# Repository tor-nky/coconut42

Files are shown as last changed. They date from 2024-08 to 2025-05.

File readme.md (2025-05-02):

# coconut42 - split ortholinear keyboard
coconut42 は左右分割式、格子配列のキーボードです。
片側ごとのキーは縦3x横6+親指3個、両側で42キーです。
本キーボードはfoostan氏が設計されたCorne Cherryのv4.1、v3-final、v2.1の公開情報を活用させていただき、キー配列とマイコンボードを変更したものです。
foostan氏のご厚意に感謝いたします。

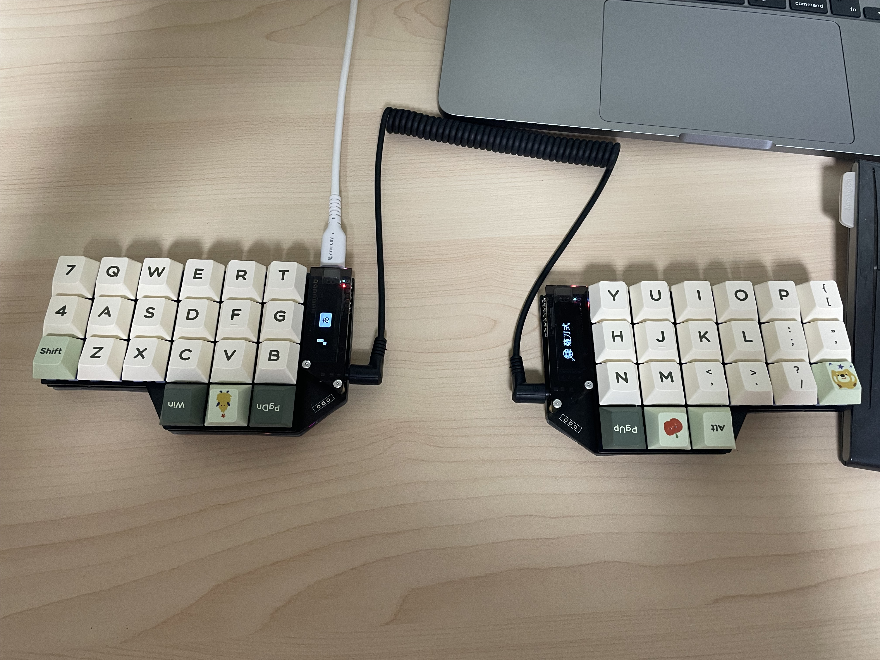
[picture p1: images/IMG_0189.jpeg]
coconut42


## 部品
### 必須
|名前|数|備考|
|:-|:-|:-|
|PCB|2枚||
|トッププレート|2枚||
|ボトムプレート|2枚||
|Seeed Studio XIAO RP2040|2枚||
|TRRSジャック|2個|MJ-4PP-9|
|ダイオード|50個|1N4148W SOD123|
|Kailh PCBソケット|42個|MX用|
|キースイッチ|42個|CherryMX互換にのみ対応 |
|キーキャップ|42個|1u|
|スペーサー M2 7.5mm全ネジ|10本||
|ネジ M2 4mm|20本||
|クッションゴム|8個||
|TRS(3極)ケーブル|1本|TRRS(4極)ケーブルでも可 |
|USB type Cケーブル |1本||
### 任意
| 名前 | 数 | 備考 |
|:-|:-|:-|
|リード線 2cm程度|2本|LEDとOLEDの電源供給用|
|抵抗1/6W470Ω|2本|R1,R6で。小さいサイズも可。やむを得ない場合ジャンパー|
|WS2812B|12個|下向き実装|
|YS-SK6812MINI-E|42個|上向き実装|
|OLEDモジュール|2枚||
|ピンヘッダ 4連|2個||
|ピンソケット4連|2個||
|OLEDカバー|2枚|Corne Cherryのものと交換可能|
|スペーサー M2 9mm全ネジ|4本||
|ネジ M2 4mm|4本||
## 注意点
* LEDまたはOLEDを取り付ける場合は、マイコンボードの裏にある「VIN」とPCBの「VIN(-r)」をリード線でつなぐ必要があります。
* LEDを取り付ける場合は、R1とR6も取り付けます。  
470Ωを入れるのは、電源供給が一瞬途絶えたときの安全対策です。
* R2,R7は、Seeed Studio XIAO ESP32C3対応を考えたためです。
* C7〜C27,C34〜C54,R3〜R5,R8〜R10は、ノイズ対策が必要になれば取り付けます。
* PCB上面のC1〜C6,C28〜C33、PCB下面のOLEDソケットそばのC55,C56は __不要__ です。
* 向きを間違えればマイコンボードを壊すので、回路図、PCBに保護ダイオードを書きませんでした。
## 別のマイコンボードへの対応
おすすめできませんが、できるものもあります。
### Seeed Studio XIAO nRF52840
ZMK Firmwareが改良二乗マトリクスに対応しています。[設定例](https://github.com/tor-nky/zmk-coconut42-ble)  
LEDは光らせられませんでした（仮にできたとしても、Blutooth通信の低下になるという）  
[左側の裏を写した写真](images/IMG_0218.jpeg) [右側の裏を写した写真](images/IMG_0215.jpeg)(マイコンボード故障でリカバリ箇所あり)
* OLED、TRRSジャックはつけない。リチウムイオン充電池を両面テープで貼り付け、プラス線は BAT+ につなぐ。マイナス線からは BAT- につなぐ途中にリセッタブルヒューズと電源スイッチを入れる。
* 左右間通信はBluetoothで行う。
* キーを押していないときにはマイコンを眠らせたいので、[Low Power Improved Square Matrix](https://kbd.news/Low-Power-Improved-Square-Matrix-1810.html)の[この回路図](https://kbd.news/pic/article/1810/4-pin-improved-square-matrix-low-power.png)のようにダイオードをマイコン取り付け部の下側につける。  
割り込みピンは左右間通信用だった「data」を流用する。
* VINにはVBUSをつなぐ
### Seeed Studio XIAO ESP32C3/6
使用できません。
### Waveshare RP2040-Zero
* 電源ピンを合わせるため、裏返してコンスルーピンヘッダを介してハンダ付けし、ピンの機能に合わせてプログラムを作り替えれば動くと思われる。
* VINにはVSYS(5V)をつなぐ
* マイコンボードを外さなければ、ファームウェアを書き込むリセットができません

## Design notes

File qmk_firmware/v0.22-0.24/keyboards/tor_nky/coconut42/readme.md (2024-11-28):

# coconut42 Keyboard

A split keyboard with 3x6 ortholiner keys and 3 thumb keys.

Keyboard Maintainer: [tor-nky](https://github.com/tor-nky/)
Hardware Supported: Seeed XIAO RP2040
Hardware Availability: [PCB & Case Data](https://github.com/tor-nky/coconut42)

Make example for this keyboard (after setting up your build environment):

```sh
make tor_nky/coconut42:default
```

See the [build environment setup](https://docs.qmk.fm/#/getting_started_build_tools) and the [make instructions](https://docs.qmk.fm/#/getting_started_make_guide) for more information. Brand new to QMK? Start with our [Complete Newbs Guide](https://docs.qmk.fm/#/newbs).

## Bootloader

The controller board have a reset and boot buttons next to the TRRS jack to enter in to the bootloader.

Additionally, if you hold down the "Q" or "P" buttons when plugging in that half of the keyboard (per the default QWERTY layout), this will jump to the bootloader and reset the EEPROM (persistent storage).  This would normally be the very top corner-most position, but due to the breakaway column, it's left at Q and P for compatibility. 

## RGB Matrix 
The coconut42 Keyboard also supports using the RGB Matrix feature, in place of RGB Light.  This provides a better experience when using the keyboard, as it supports a number of per key effects properly.  If you're not using the in switch LEDs, then you may want to pass on doing this. 

In your keymap's `rules.mk` file, add the following: 

```make
RGBLIGHT_ENABLE = no
RGB_MATRIX_ENABLE = yes
```

And in your `config.h` file, add the following:

```c

#ifdef RGB_MATRIX_ENABLE
#   define RGB_MATRIX_KEYPRESSES // reacts to keypresses
// #   define RGB_MATRIX_KEYRELEASES // reacts to keyreleases (instead of keypresses)
#   define RGB_MATRIX_SLEEP // turn off effects when suspended
#   define RGB_MATRIX_FRAMEBUFFER_EFFECTS
// #   define RGB_MATRIX_LED_PROCESS_LIMIT (RGB_MATRIX_LED_COUNT + 4) / 5 // limits the number of LEDs to process in an animation per task run (increases keyboard responsiveness)
// #   define RGB_MATRIX_LED_FLUSH_LIMIT 16 // limits in milliseconds how frequently an animation will update the LEDs. 16 (16ms) is equivalent to limiting to 60fps (increases keyboard responsiveness)
#    define RGB_MATRIX_MAXIMUM_BRIGHTNESS 150 // limits maximum brightness of LEDs to 150 out of 255. Higher may cause the controller to crash. 
#    define RGB_MATRIX_HUE_STEP 8
#    define RGB_MATRIX_SAT_STEP 8
#    define RGB_MATRIX_VAL_STEP 8
#    define RGB_MATRIX_SPD_STEP 10

/* Enable the animations you want/need.  You may need to enable only a small number of these because       *
 * they take up a lot of space.  Enable and confirm that you can still successfully compile your firmware. */
// RGB Matrix Animation modes. Explicitly enabled
// For full list of effects, see:
// https://docs.qmk.fm/#/feature_rgb_matrix?id=rgb-matrix-effects
#    define ENABLE_RGB_MATRIX_ALPHAS_MODS
#    define ENABLE_RGB_MATRIX_GRADIENT_UP_DOWN
#    define ENABLE_RGB_MATRIX_GRADIENT_LEFT_RIGHT
#    define ENABLE_RGB_MATRIX_BREATHING
#    define ENABLE_RGB_MATRIX_BAND_SAT
#    define ENABLE_RGB_MATRIX_BAND_VAL
#    define ENABLE_RGB_MATRIX_BAND_PINWHEEL_SAT
#    define ENABLE_RGB_MATRIX_BAND_PINWHEEL_VAL
#    define ENABLE_RGB_MATRIX_BAND_SPIRAL_SAT
#    define ENABLE_RGB_MATRIX_BAND_SPIRAL_VAL
#    define ENABLE_RGB_MATRIX_CYCLE_ALL
#    define ENABLE_RGB_MATRIX_CYCLE_LEFT_RIGHT
#    define ENABLE_RGB_MATRIX_CYCLE_UP_DOWN
#    define ENABLE_RGB_MATRIX_RAINBOW_MOVING_CHEVRON
#    define ENABLE_RGB_MATRIX_CYCLE_OUT_IN
#    define ENABLE_RGB_MATRIX_CYCLE_OUT_IN_DUAL
#    define ENABLE_RGB_MATRIX_CYCLE_PINWHEEL
#    define ENABLE_RGB_MATRIX_CYCLE_SPIRAL
#    define ENABLE_RGB_MATRIX_DUAL_BEACON
#    define ENABLE_RGB_MATRIX_RAINBOW_BEACON
#    define ENABLE_RGB_MATRIX_RAINBOW_PINWHEELS
#    define ENABLE_RGB_MATRIX_RAINDROPS
#    define ENABLE_RGB_MATRIX_JELLYBEAN_RAINDROPS
#    define ENABLE_RGB_MATRIX_HUE_BREATHING
#    define ENABLE_RGB_MATRIX_HUE_PENDULUM
#    define ENABLE_RGB_MATRIX_HUE_WAVE
#    define ENABLE_RGB_MATRIX_PIXEL_RAIN
#    define ENABLE_RGB_MATRIX_PIXEL_FLOW
#    define ENABLE_RGB_MATRIX_PIXEL_FRACTAL
// enabled only if RGB_MATRIX_FRAMEBUFFER_EFFECTS is defined
#    define ENABLE_RGB_MATRIX_TYPING_HEATMAP
#    define ENABLE_RGB_MATRIX_DIGITAL_RAIN
// enabled only of RGB_MATRIX_KEYPRESSES or RGB_MATRIX_KEYRELEASES is defined
#    define ENABLE_RGB_MATRIX_SOLID_REACTIVE_SIMPLE
#    define ENABLE_RGB_MATRIX_SOLID_REACTIVE
#    define ENABLE_RGB_MATRIX_SOLID_REACTIVE_WIDE
#    define ENABLE_RGB_MATRIX_SOLID_REACTIVE_MULTIWIDE
#    define ENABLE_RGB_MATRIX_SOLID_REACTIVE_CROSS
#    define ENABLE_RGB_MATRIX_SOLID_REACTIVE_MULTICROSS
#    define ENABLE_RGB_MATRIX_SOLID_REACTIVE_NEXUS
#    define ENABLE_RGB_MATRIX_SOLID_REACTIVE_MULTINEXUS
#    define ENABLE_RGB_MATRIX_SPLASH
#    define ENABLE_RGB_MATRIX_MULTISPLASH
#    define ENABLE_RGB_MATRIX_SOLID_SPLASH
#    define ENABLE_RGB_MATRIX_SOLID_MULTISPLASH
#endif
```

After this is done, you should be able to use the normal RGB keycodes, but you'll see the RGB Matrix effects in use, giving a much better experience.

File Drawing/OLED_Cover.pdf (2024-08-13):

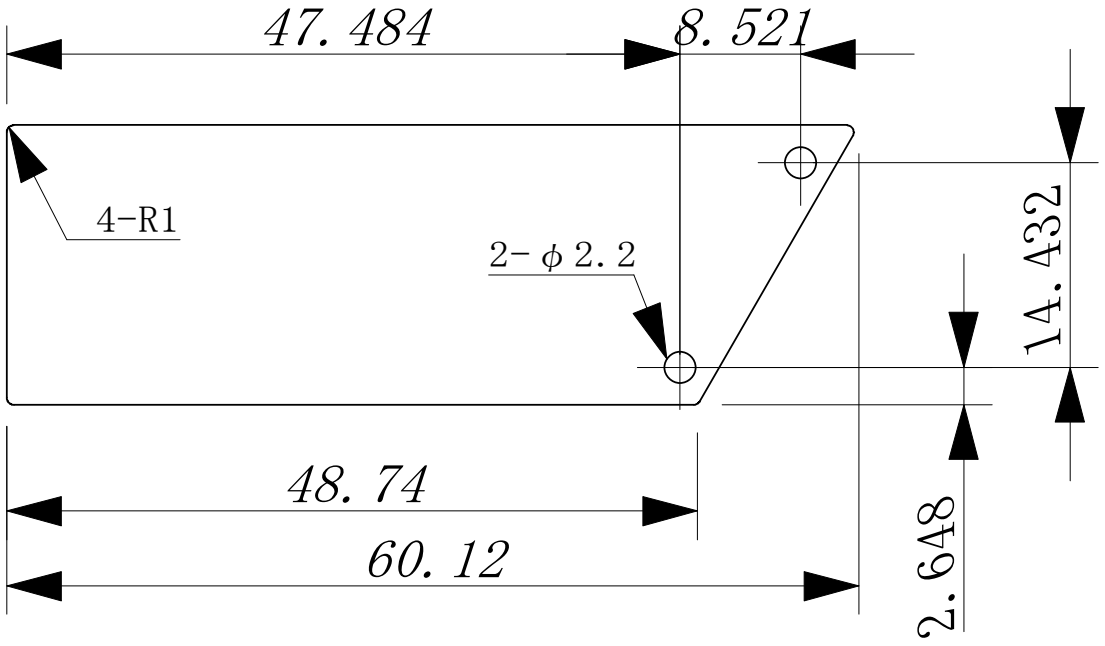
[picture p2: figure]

数量：左右対称1枚ずつ

材質：任意
厚さ：2.0程度

19.718

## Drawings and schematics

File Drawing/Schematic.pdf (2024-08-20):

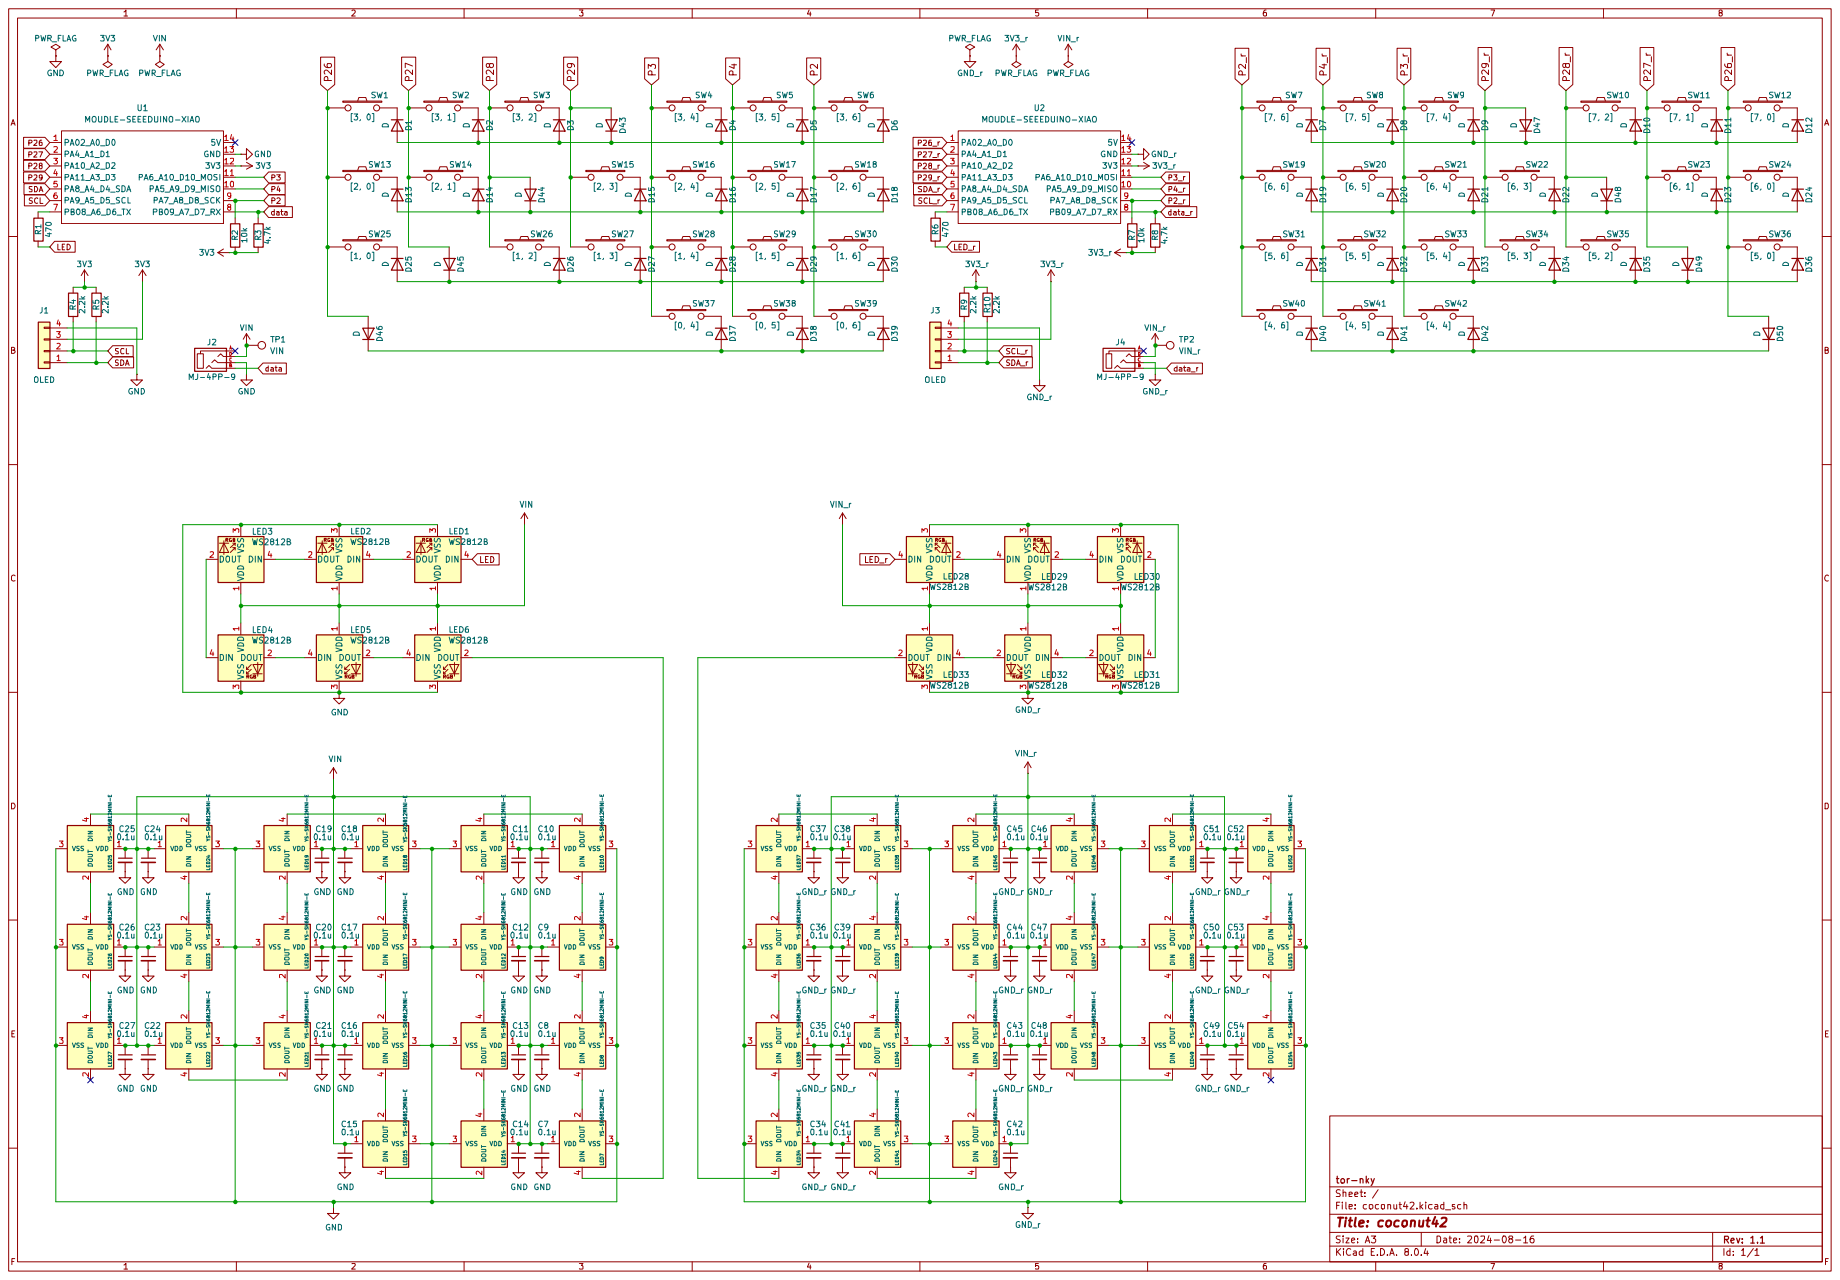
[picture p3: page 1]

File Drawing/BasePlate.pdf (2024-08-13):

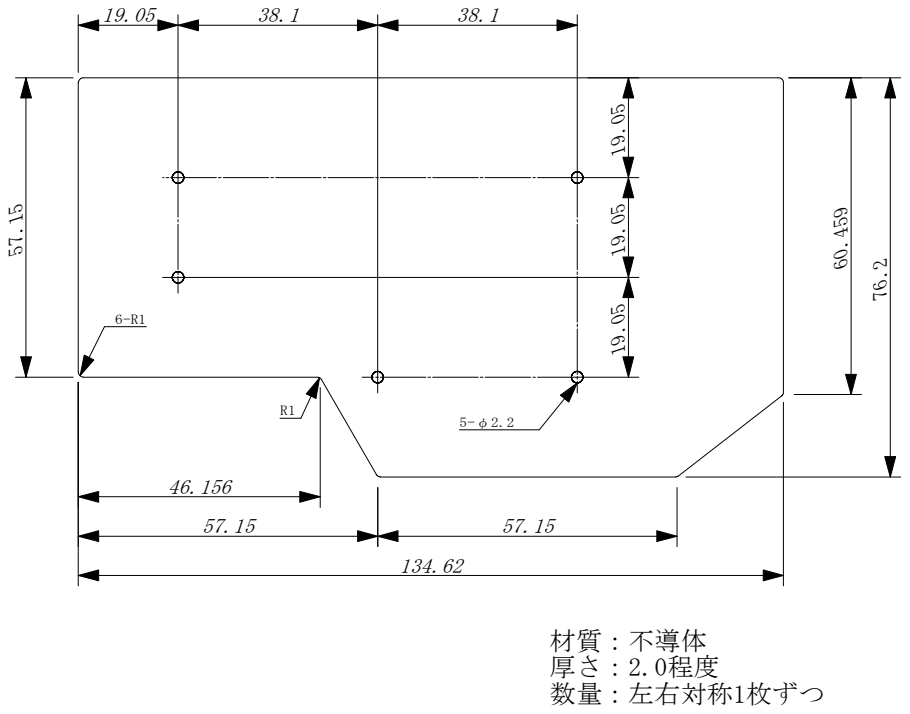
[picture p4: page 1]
数量：左右対称1枚ずつ; 材質：不導体 厚さ：2.0程度

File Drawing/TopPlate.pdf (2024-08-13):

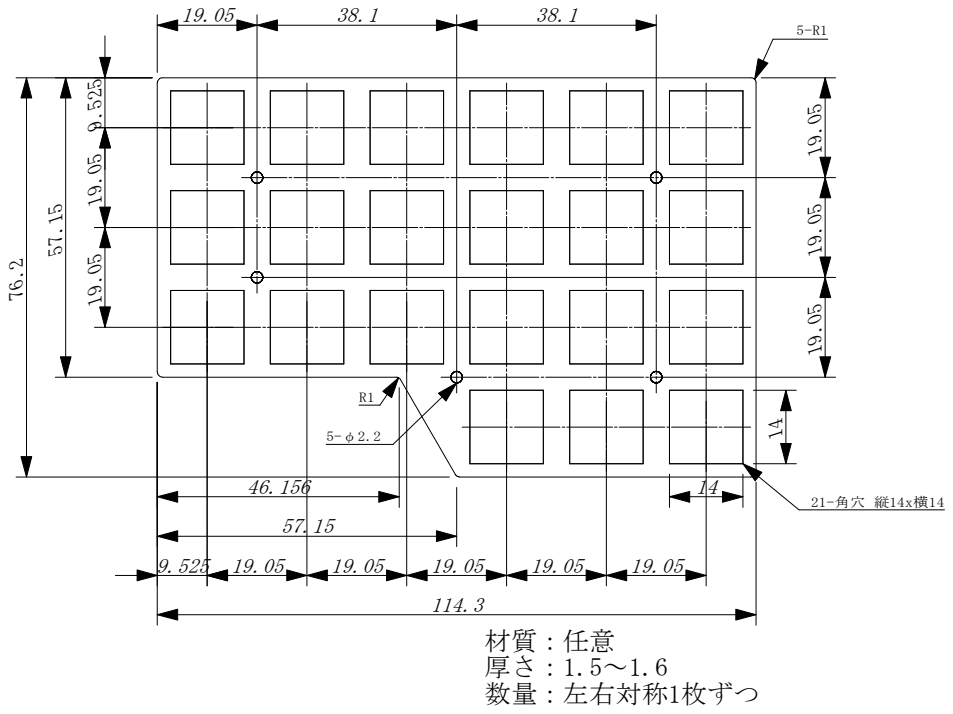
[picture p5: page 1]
数量：左右対称1枚ずつ

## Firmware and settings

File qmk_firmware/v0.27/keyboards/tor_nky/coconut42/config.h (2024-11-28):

// Copyright 2024 QMK
// SPDX-License-Identifier: GPL-2.0-or-later

#pragma once

#define I2C_DRIVER I2CD1
#define I2C1_SDA_PIN GP6
#define I2C1_SCL_PIN GP7

/* RP2040- and hardware-specific config */
#define PICO_XOSC_STARTUP_DELAY_MULTIPLIER 64

#define MATRIX_MASKED

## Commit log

2024-08-13 別のマイコンボードへの対応を構想
2024-08-16 v1.1: OLEDの電源を+3.3Vにするなど
    [coconut42.kicad_sch, coconut42_TopPlate.kicad_pcb]
2024-08-20 名称を統一
    [coconut42.kicad_sch]
2024-08-20 回路図のPDF
2024-08-21 レイアウト順を入れ替え
2024-09-03 文書書き換え
2024-09-03 QMK Firmware v0.26対応
2024-09-18 PCB Rev1.2
2024-10-05 別のマイコンボードへの対応を書き換え
2024-11-23 PCB Rev.1.3
2024-11-23 XIAO BLE取り付け改造例
2024-11-23 改造例の写真は表示しない
2024-11-28 QMK Firmware対応のバージョン履歴
2024-11-29 naginata_v15mキーマップを削除
2025-05-02 写真入れ換え
